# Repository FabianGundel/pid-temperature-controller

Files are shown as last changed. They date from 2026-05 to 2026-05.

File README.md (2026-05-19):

# PID Temperature Controller – Water Bath System

> This project is currently work in progress.
> Source code and additional documentation will be uploaded progressively during development.

## Project Overview

This project is a self-developed **PID-based temperature control system** for a water bath, implemented using an Arduino UNO.

The goal is precise temperature regulation of a 1L water container using a self-calibrated NTC thermistor and a PWM-controlled heating element.

This project is being build to better understand practical control engineering, temperature measurement, PWM power control and sensor calibration. Instead of using a ready-made thermostat module, the entire control loop is being implemented using an Arduino UNO, a MOSFET-driven heating element and a self-calibrated NTC thermistor.

---

## Project Objectives

- Design and implementation of a closed-loop control system
- Development of a PID control algorithm
- Calibration of an NTC temperature sensor [NTC-Calibration](docs/calibration.md)
- Implementation of PWM-based power control

---

## Hardware

[Hardware](hardware/pid-temperature-controller-hardware.pdf)

---

## Circuit

[Main Circuit Diagram](docs/main.pdf)

---

## Code

[PID-Temperature-Regulation Code](src/main/main.ino)

---

## System Architecture

### 1. Temperature Measurement
- Waterproof 10kΩ NTC thermistor (25°C reference)
- 2660Ω reference resistor
- Temperature calculation using the Steinhart–Hart equation

### 2. Signal Processing
- Arduino UNO microcontroller
- Real-time temperature computation
- Error calculation (setpoint vs. measured value)
- PID control algorithm

### 3. Power Stage
- MOSFET: IRLB8743
- PWM-controlled switching
- Heating element: 12V / 40W epoxy-sealed heater
- Power supply: 12V / 60W

### 4. Actuator
- Immersed heating element inside the water bath

---

## Current Status

✔ Hardware fully assembled 
✔ MOSFET successfully tested 
✔ NTC sensor calibrated 
✔ Temperature measurement functional 
- Control algorithm implementation ongoing 
- PID parameter tuning ongoing 

---

## License

MIT

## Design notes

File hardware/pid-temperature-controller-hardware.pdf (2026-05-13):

Component | Model/Specification | Quantity | Notes
Microcontroller | Arduino UNO | 1 | -
Temperature Sensor [TH1] | 10K Waterproof NTC | 1 | -
Reference Resistor [R1] | 2660R | 1 | -
Gate Resistor [R2] | 100R | 1 | -
Pull-Down Resistor [R3] | 10K | 1 | -
Power MOSFET [Q1] | IRLB8743 | 1 | -
Heating Element [H1] | 12V/40W | 1 | Epoxy sealed
Power Supply | 12V/60W | 1 | -
Breadboard | Standart | 1 | -
Jumper Wires | - | Set | -
Water Container | 1L; Glass | 1 | -

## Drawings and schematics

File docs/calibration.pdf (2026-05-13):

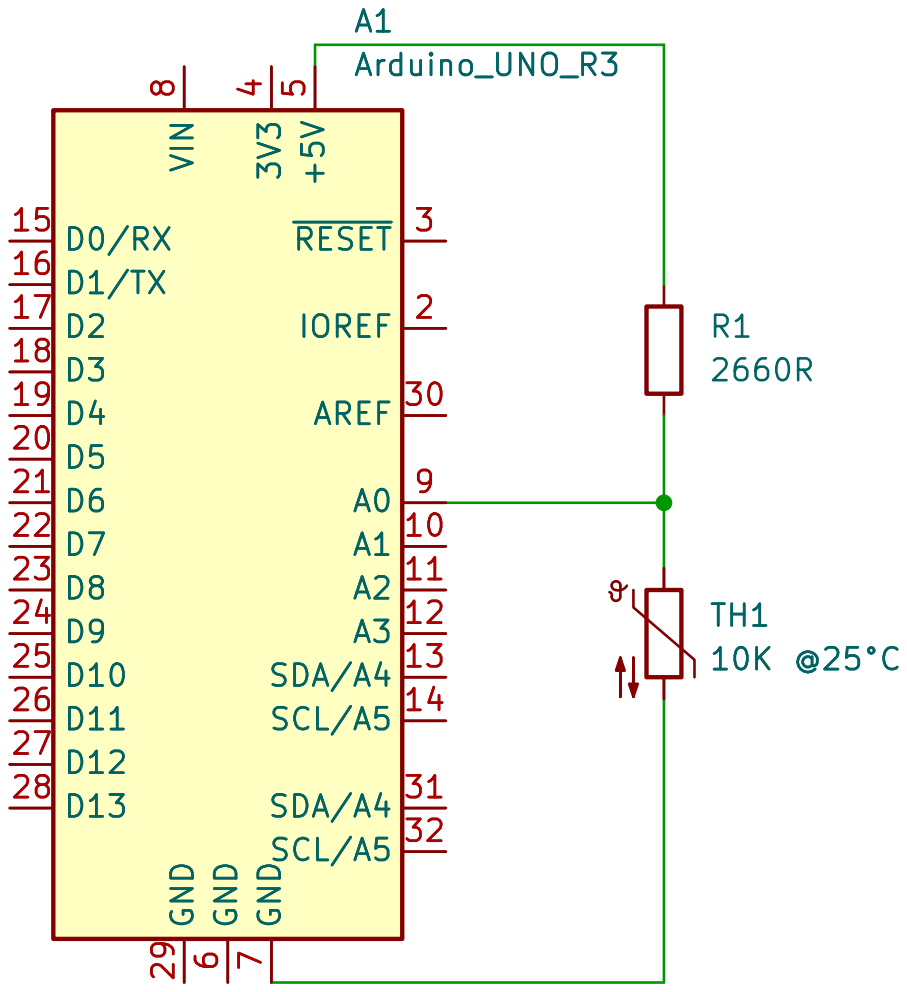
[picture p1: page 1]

Sheet: /
D Date: 2026-05-13 KiCad E.D.A. 10.0.0
File: calibration.kicad_sch
Title: pid-temperature-controller|ntc-calibration

Size: A4 | Rev: v1.1

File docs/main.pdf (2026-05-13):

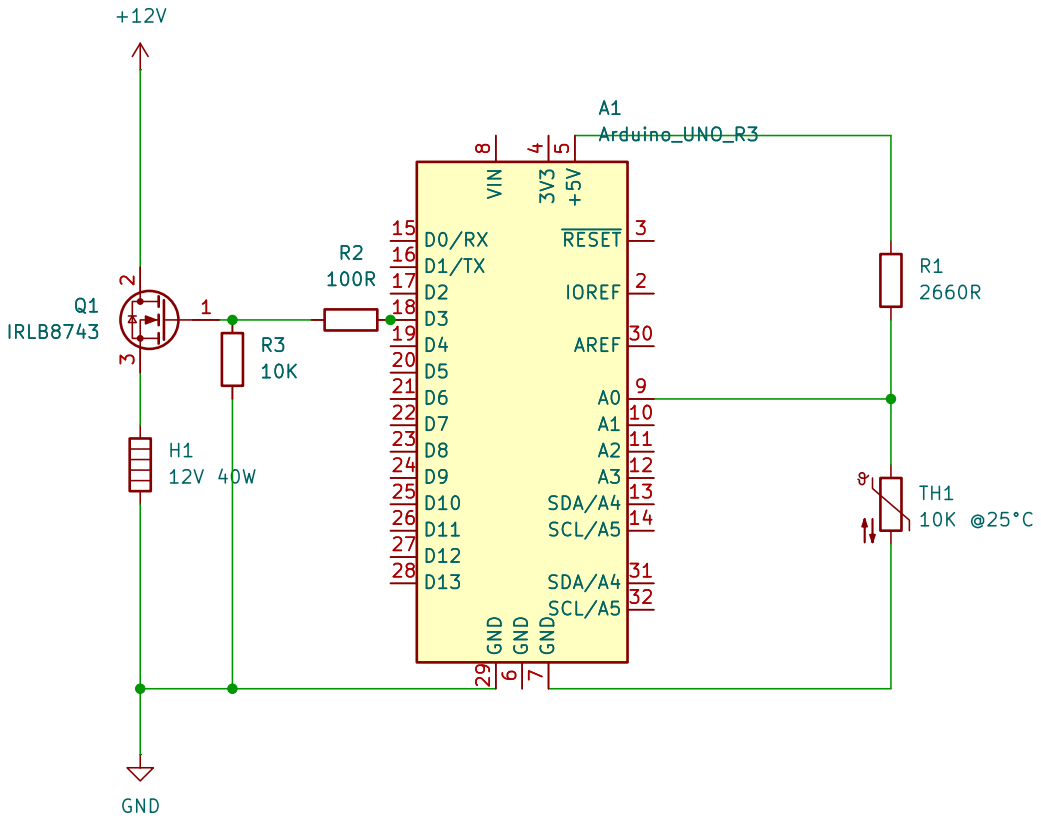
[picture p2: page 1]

Sheet: /
D Date: 2026-05-13 KiCad E.D.A. 10.0.0
File: main.kicad_sch
Title: pid-temperature-controller|main

Size: A4 | Rev: v1.1

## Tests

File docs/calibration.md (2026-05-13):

# NTC Thermistor Calibration

Calibration of a NTC thermistor using the Steinhart-Hart equation for the water bath PID controller.

## Components

- NTC Thermistor: 10kΩ @ 25°C
- Reference resistor: 2660Ω
- Arduino Uno
- Reference thermometer

## Circuit

[Calibration Circuit Diagram](../docs/calibration.pdf)
 
## Code

[Calibration Code](../src/calibration/calibration.ino)

## Calibration Data

| T (°C) | avg ADC Raw | R_NTC (Ω) |
|---|---|---|
| 29.6 | 762.0 | 7794 |
| 61.8 | 456.8 | 2146 |
| 85.5 | 280.0 | 1002 |

## Steinhart-Hart Coefficients

The coefficients were calculated from three reference temperature points
using nonlinear curve fitting based on the Steinhart-Hart model.

Calculated using the [Thermistor Calculator by Stanford Research Systems Inc](https://www.thinksrs.com/downloads/programs/therm%20calc/ntccalibrator/ntccalculator.html)
> **Note:** If the link is unavailable, coefficients can be recalculated using any
> Steinhart-Hart solver using the calibration data.

| Coefficient | Value |
|---|---|
| A | +7.927e-4 |
| B | +3.015e-4 |
| C | -2.659e-7 |

## Formula

1/T = A + B·ln(R) + C·ln(R)³

## Results

- Max. deviation: ±0.5°C in the range 20–90°C
- Used ADC range: 254-842

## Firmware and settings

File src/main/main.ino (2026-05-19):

// work in progress
//--------------------------------------------------------------


//pid parameter
double Kp = 0.0;//insert Kp;
double Ki = 0.0;//insert Ki;
double Kd = 0.0;//insert Kd;

//temperature
double setpoint = 50.0; // °C (<= 90°C !!!)
const int NUM_READS = 5;
const double TEMP_MAX = 95.0; // °C

//steinhart-hart
const double A = 0.0007927;
const double B = 0.0003015;
const double C = -0.0000002659;

//hardware
const int PIN_NTC = A0;
const int PIN_MOSFET = 9;

const double V_REF = 5.0;
const double R_REF = 2660.0;

//intern

double temperature = 0.0;
double lastPrintedTemp = 0.0;

double errorPid = 0.0;
double previousError = 0.0;

double integral = 0.0;
double derivative = 0.0;

double output = 0.0;

unsigned long previousTime = 0;

//setup

void setup() {

  Serial.begin(115200);

  pinMode(PIN_MOSFET, OUTPUT);

  analogWrite(PIN_MOSFET, 0);

  previousTime = millis();

  Serial.println("PID Temperaturcontroller gestartet");
}

//loop
void loop() {

  //time
  unsigned long currentTime = millis();
  double dt = (currentTime - previousTime) / 1000.0;

  if (dt <= 0.0) return;

  previousTime = currentTime;

  temperature = readTemperature();

  //safety cutoff
  if (temperature > TEMP_MAX) {
    Serial.println("WARNING: Temperature is too high!");
    while (true) {
      analogWrite(PIN_MOSFET, 0);
    } 
  }

  //pid controll calculation
  errorPid = setpoint - temperature;

  derivative = (errorPid - previousError) / dt;

  double rawOutput = (Kp * errorPid) + (Ki * integral) + (Kd * derivative);

  if (rawOutput > 0 && rawOutput < 255) { 
    integral += errorPid * dt; 
    
    rawOutput = (Kp * errorPid) + (Ki * integral) + (Kd * derivative);
  } //integral only for finetuning

  
  previousError = errorPid;

  //pwm output
  output = constrain(rawOutput, 0, 255);

  analogWrite(PIN_MOSFET, (int)output);

  //serial output
  if (abs(temperature - lastPrintedTemp) > 0.1) {

    Serial.println("Setpoint: " + String(setpoint) + "°C");
    Serial.println("Process: " + String(temperature) + "°C");
    Serial.println("PWM: " + String(output));
    Serial.println("Error: " + String(errorPid));
    Serial.println("---------------------------------------");

    lastPrintedTemp = temperature;
  }
  
  
}


//temperature measurement
double readTemperature() {

  long sum = 0;
  for (int i = 0; i < NUM_READS; i++) {
    sum += analogRead(PIN_NTC);
    delay(10);
  }
  float adc_avg = (float)sum / NUM_READS;

  adc_avg = constrain(adc_avg, 1, 1022);

 
  double voltage =
    (adc_avg * V_REF) / 1023.0;

 
  double ntcResistance =
    R_REF * ((V_REF / voltage) - 1.0);

 
  double lnR = log(ntcResistance);

  double temperatureKelvin =
    1.0 / (A + (B * lnR) + (C * lnR * lnR * lnR));

  double temperatureCelsius = temperatureKelvin - 273.15;

  return temperatureCelsius;
}

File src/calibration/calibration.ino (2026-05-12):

const int   PIN_NTC   = A0;      // analog input pin between R_ref and R_NTC
const float R_REF     = 2660.0;  // reference resistor value
const int   ADC_MAX   = 1023;
const int   NUM_READS = 10;      // number of measurements in N to calculate average ADC

void setup() {

  Serial.begin(9600);
  while (!Serial);  

  Serial.println("========================================");
  Serial.println("   NTC Calibration - Measurement Tool   ");
  Serial.println("========================================");
  Serial.println("----------------------------------------");
  Serial.println("    [type 'm' to start measurement]     ");
  Serial.println("----------------------------------------");
}

void loop() {

  // waiting for user input
  if (Serial.available() > 0) {
    char input = Serial.read();

    if (input == 'm' || input == 'M') {
      measurement();
    } 
  }
}

void measurement() {

  // measuring several ADC values and calculating ADC average 
  long sum = 0;
  for (int i = 0; i < NUM_READS; i++) {
    sum += analogRead(PIN_NTC);
    delay(10);
  }
  float adc_avg = (float)sum / NUM_READS;

  // calculating NTC resistance
  float R_ntc = R_REF * (adc_avg / (ADC_MAX - adc_avg));

  // output
  Serial.println("ADC_raw (avg): " + String(adc_avg));
  Serial.println("R_NTC: " + String(R_ntc) + " Ohm");
  Serial.println("----------------------------------------");
  Serial.println("    [type 'm' to start measurement]     ");
  Serial.println("----------------------------------------");
}

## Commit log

2026-05-09 add calibration documentation
2026-05-11 added hardware files & removed dead links
    [pid-temperature-controller-hardware.xlsx]
2026-05-12 add calibration code & link
2026-05-13 add main/calibration circuit diagram & links
    [calibration.kicad_sch, main.kicad_sch]
2026-05-13 edit components & main circuit
    [main.kicad_sch, pid-temperature-controller-hardware.xlsx]
2026-05-19 add empty pid.md
